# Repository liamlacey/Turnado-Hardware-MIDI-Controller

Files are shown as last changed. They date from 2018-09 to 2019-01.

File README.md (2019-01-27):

# Turnado Hardware MIDI Controller

This project is the development of a dedicated hardware MIDI controller for [Turnado](https://sugar-bytes.de/turnado) - a multi-award winning, real-time multi audio effect software plugin, developed by Berlin-based company Sugar Bytes. 

This was a project developed for the 2018 Hackaday Prize and was awarded as one of the top 20 projects for the Musical Instrument Challenge - see the project page [here](https://hackaday.io/project/160792-turnado-hardware-midi-controller).

This repo includes all code and design files for the project.

The project uses a [Teensy 3.6](https://www.pjrc.com/teensy/) microcontoller, and requries the following software and libraries to compile the code:
- [Arduino IDE](https://www.arduino.cc/en/Main/Software)
- [Teensyduino](https://www.pjrc.com/teensy/td_download.html) software add-on for Arduino IDE
- [Optimized ILI9341 TFT Library](https://github.com/PaulStoffregen/ILI9341_t3) for Arduino

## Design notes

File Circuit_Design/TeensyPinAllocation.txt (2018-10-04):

0 / RX1 	- UNUSED (keep spare for MIDI)
1 / TX1  	- UNUSED (keep spare for MIDI)
2 		- Preset down button
3 		- Preset up button
4 		- Randomise button
5 		- LCD enc 3 A
6 		- LCD enc 3 B
7 		- LCD enc 2 A
8 		- LCD enc 2 B
9 		- LCD D/C
10 / CS0 	- LCD CS
11 / MOSI0 	- LCD DSI/MOSI
12 / MISO0 	- LCD SDO/MISO
13 / SCK0 	- LCD SCK
14 / A0 	- Enc 6 switch
15 / A1 	- Enc 7 B
16 / A2 	- Enc 7 A
17 / A3 	- Enc 7 switch
18 / A4 	- JS 7
19 / A5 	- Enc 8 B
20 / A6 	- Enc 8 A
21 / A7 	- Enc 8 switch
22 / A8 	- JS 8
23 / A9 	- UNUSED 
24 		- LCD enc 1 switch
25 		- LCD enc 1 A 
26 		- LCD enc 1 B
27 		- Mix enc A
28 		- Mix enc B
29 		- Dictator enc switch
30 		- Dictator enc A
31 / A12 	- Dictator enc B
32 / A13 	- Dictator JS
33 / A14 	- JS 3
34 / A15 	- JS 4
35 / A16 	- Enc 5 B
36 / A17 	- Enc 5 A
37 / A18 	- Enc 5 switch
38 / A19 	- Enc 6 B
39 / A20 	- Enc 6 A
A21 		- JS 5
A22 		- JS 6

Inner row through-hole pins:
A10 		- UNUSED
A11 		- UNUSED

Surface mount pins:
40 		- Enc 1 A
41 		- Enc 2 B
42 		- Enc 2 switch
43 		- Enc 3 B
44 		- Enc 3 A
45 		- Enc 4 B
46 		- Enc 4 switch
47 		- Enc 4 A
48 		- Enc 3 switch
49 / A23 	- JS 2
50 / A24 	- JS 1
51 		- Enc 2 A
52 		- Enc 1 switch
53 		- Enc 1 B
54 		- UNUSED
55 		- UNUSED
56 		- UNUSED
57 		- UNUSED

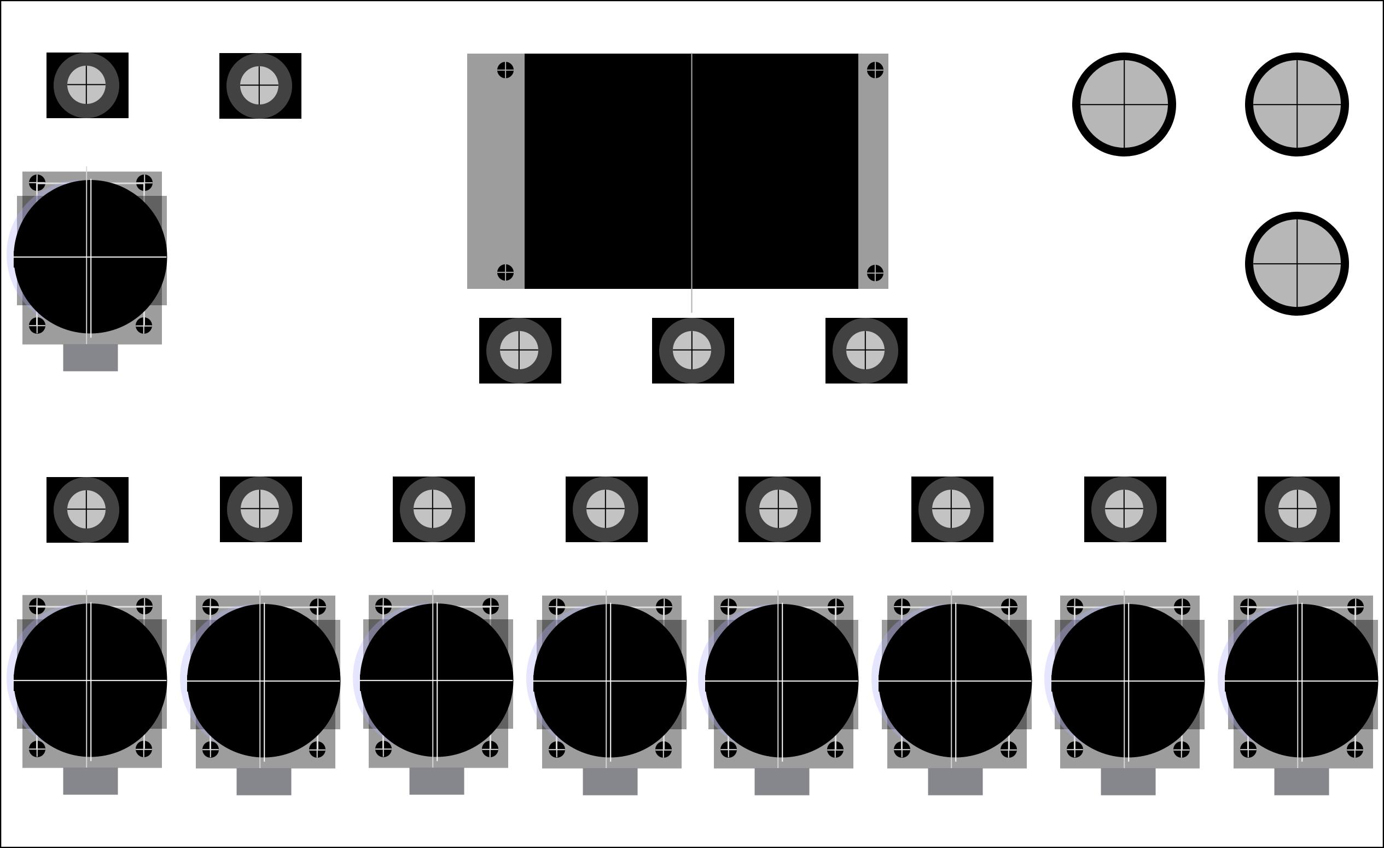
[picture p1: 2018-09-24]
Panel_Design/TurnadoHardwareControllerControlLayoutv2.png

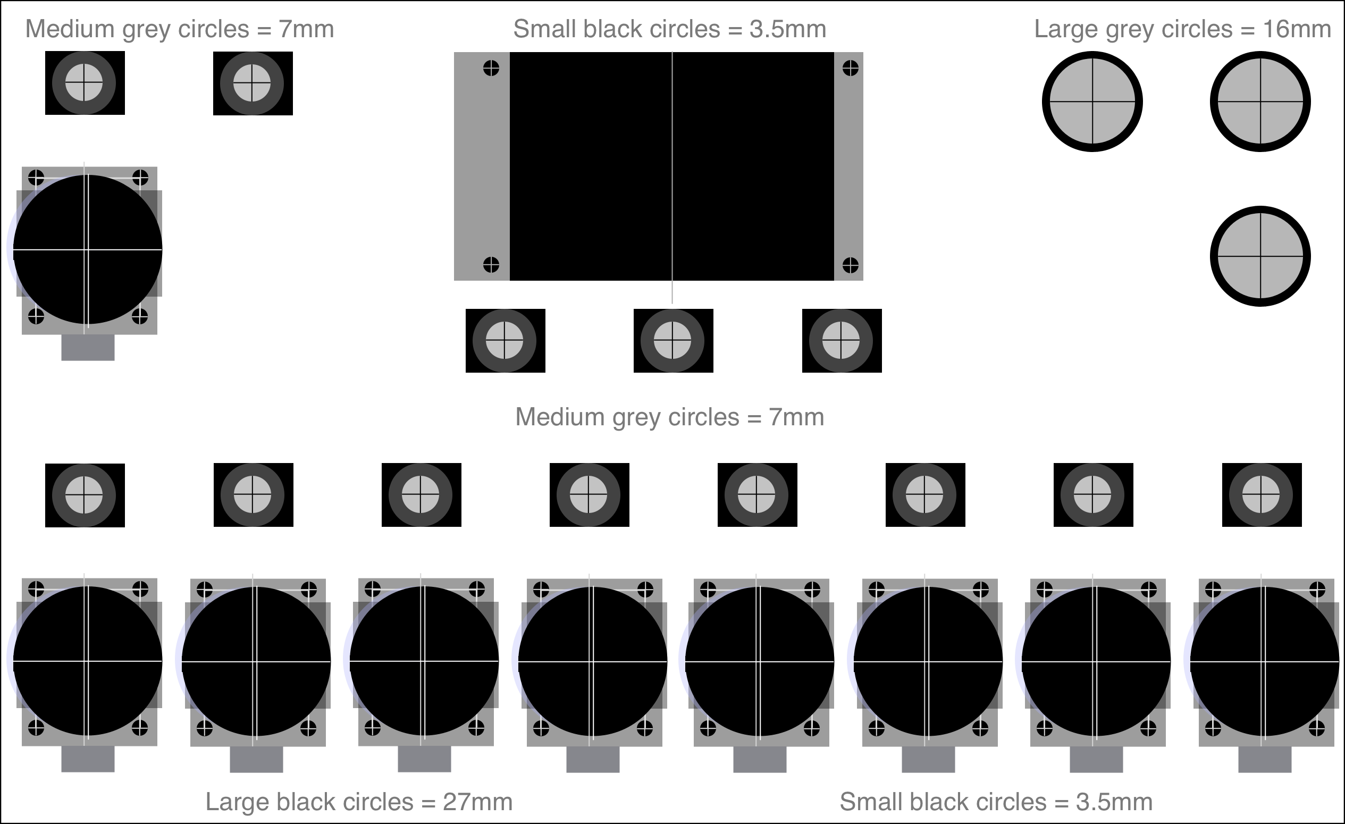
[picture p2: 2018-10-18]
Panel_Design/TurnadoHardwareControllerControlLayoutv2Annotated.png

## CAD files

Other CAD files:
Panel_Design/TurnadoHardwareControllerPanelHoles.dwg

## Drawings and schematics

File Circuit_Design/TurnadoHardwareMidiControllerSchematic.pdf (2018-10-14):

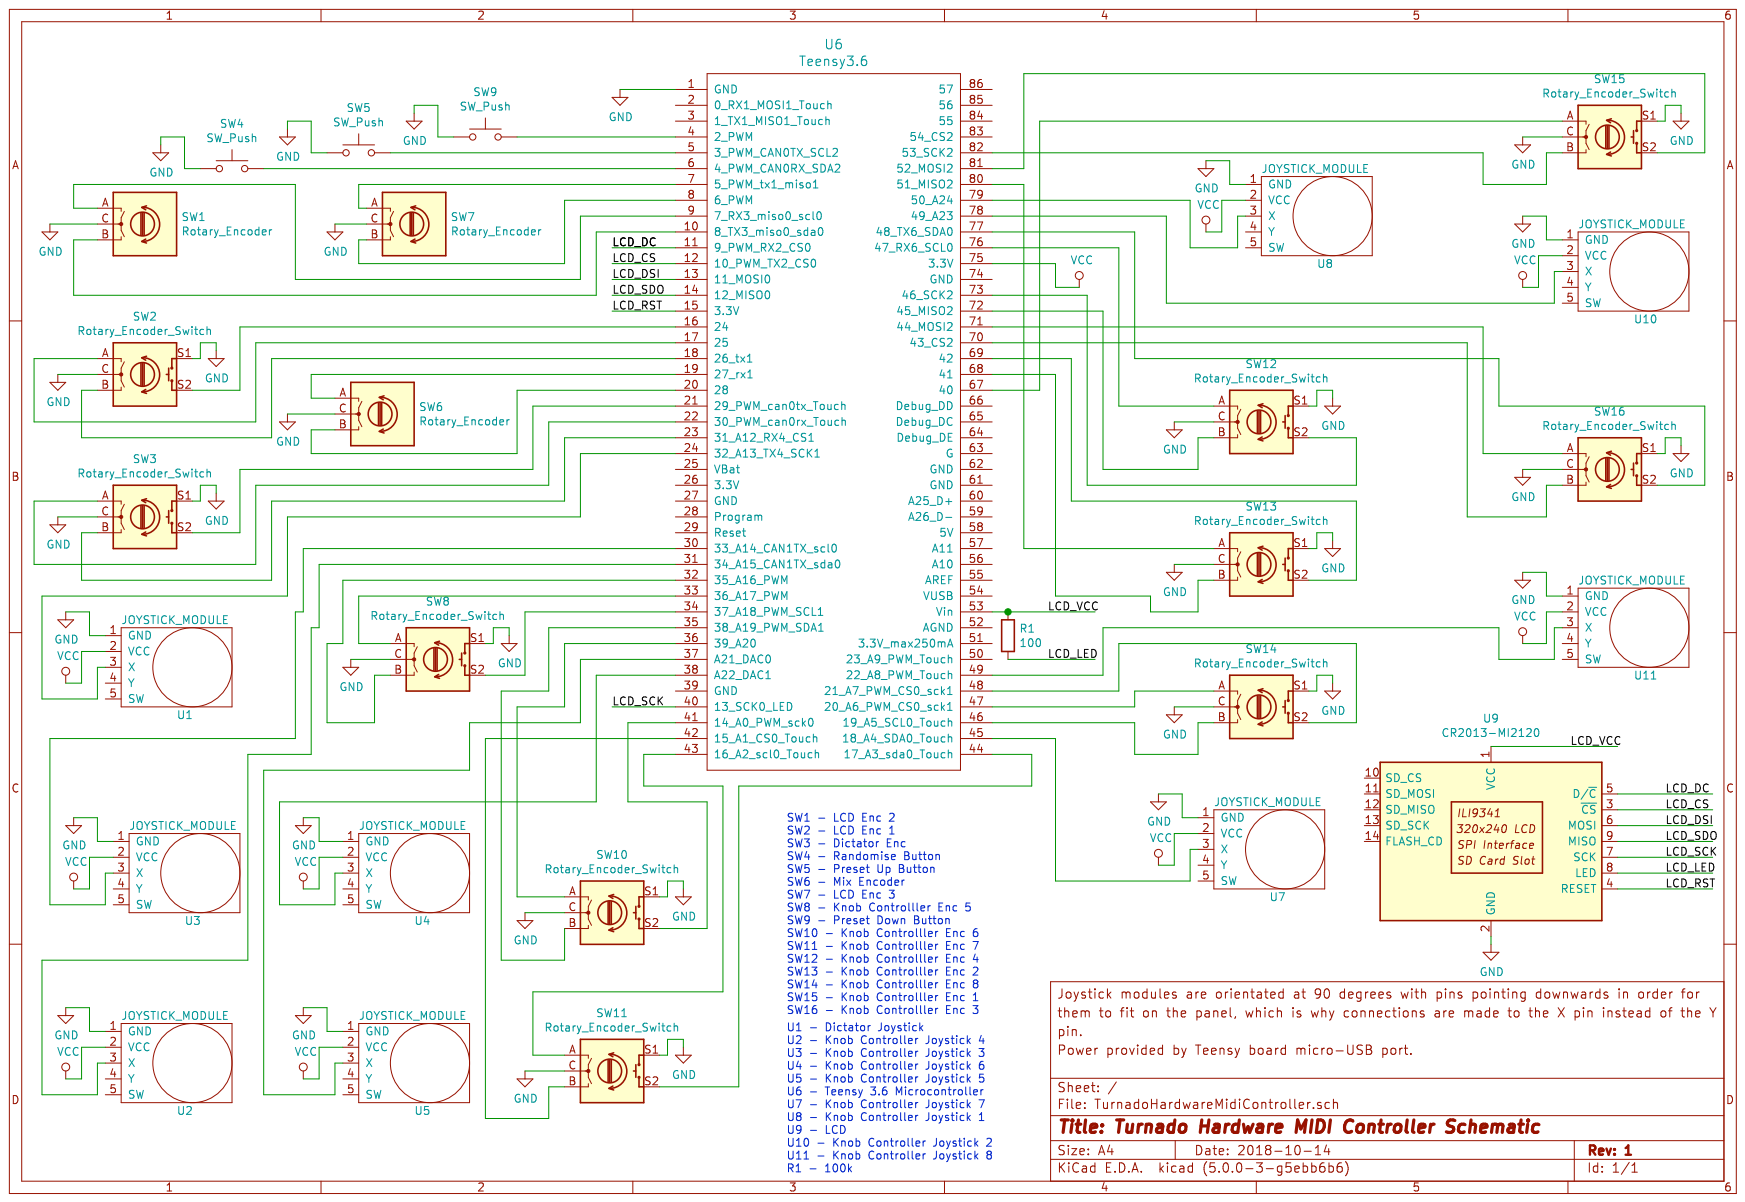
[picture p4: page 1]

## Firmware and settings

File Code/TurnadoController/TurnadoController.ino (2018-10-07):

#include "Globals.h"

//=========================================================================
//FIXME: make the below an array for each MIDI channel, where the index is set by the current MIDI channel of the program change buttons.
//This will involve needing to update the program display on the LCD top bar every time the program change buttons MIDI channel is changed.
int16_t currentMidiProgramNumber = 0;

//FIXME: could the below be replaced by knobControllerData and mixControllerData as arrays for each MIDI channel?
uint8_t deviceParamValuesForMidiChannel[16][NUM_OF_DEVICE_PARAMS] = {{0}};

//=========================================================================
#include "PinAllocations.h"
#include "Settings.h"

void setKnobControllerBaseValue (uint8_t index, uint8_t value, bool sendToMidiOut);
void setMixControllerValue (uint8_t value, bool sendToMidiOut);

#include "MidiIO.h"
#include "Lcd.h"
#include "Controls.h"

//=========================================================================
//=========================================================================
//=========================================================================
void setup()
{
#ifdef DEBUG
  Serial.begin(9600);
  delay(500);
#endif

  setupSettings();
  setupLcd();
  setupControls();
  setupMidiIO();

  for (uint8_t chan = 0; chan < 16; chan++)
  {
    //assume mix value always starts at 127, and the rest start at 0.
    deviceParamValuesForMidiChannel[chan][DEVICE_PARAM_INDEX_MIX] = 127;
  }
}

//=========================================================================
//=========================================================================
//=========================================================================
void loop()
{
  updateMidiIO();
  updateControls();
  updateLcd();
  settingsUpdateEeprom();
}

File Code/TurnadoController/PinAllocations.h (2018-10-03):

struct EncoderPins
{
  uint8_t pinA;
  uint8_t pinB;
  int8_t pinSwitch;
};

const EncoderPins PINS_KNOB_CTRL_ENCS[NUM_OF_KNOB_CONTROLLERS] =
{
  {.pinA = 40, .pinB = 53, .pinSwitch = 52}, //1
  {.pinA = 51, .pinB = 41, .pinSwitch = 42}, //2
  {.pinA = 44, .pinB = 43, .pinSwitch = 48}, //3
  {.pinA = 47, .pinB = 45, .pinSwitch = 46}, //4
  {.pinA = 36, .pinB = 35, .pinSwitch = 37}, //5
  {.pinA = 39, .pinB = 38, .pinSwitch = 14}, //6
  {.pinA = 16, .pinB = 15, .pinSwitch = 17}, //7
  {.pinA = 20, .pinB = 19, .pinSwitch = 21}, //8
  {.pinA = 30, .pinB = 31, .pinSwitch = 29}  //dictator
};

const EncoderPins PINS_MIX_ENC =
{
  .pinA = 27,
  .pinB = 28,
  .pinSwitch = -1
};

const EncoderPins PINS_LCD_ENCS[NUM_OF_LCD_ENCS] =
{
  {.pinA = 25, .pinB = 26, .pinSwitch = 24},  //Control
  {.pinA = 7, .pinB = 8, .pinSwitch = -1},    //Paramater
  {.pinA = 5, .pinB = 6, .pinSwitch = -1},    //Value

};

const uint8_t PINS_KNOB_CTRL_JOYSTICKS[NUM_OF_KNOB_CONTROLLERS] =
{
  A24, //1
  A23, //2
  A14, //3
  A15, //4
  A21, //5
  A22, //6
  A4,  //7
  A8,  //8
  A13, //dictator
};

const uint8_t PIN_PRESET_UP_BUTTON = 3;
const uint8_t PIN_PRESET_DOWN_BUTTON = 2;

const uint8_t PIN_RANDOMISE_BUTTON = 4;

const uint8_t PIN_LCD_DC = 9;
const uint8_t PIN_LCD_CS = 10;

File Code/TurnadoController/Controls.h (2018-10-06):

#include "RotaryEncoder.h"
#include "SwitchControl.h"
#include "ThumbJoystick.h"

//=========================================================================
//DEV STUFF...
//#define DISABLE_JOYSTICKS 1

//=========================================================================
RotaryEncoder* knobControllersEncoders[NUM_OF_KNOB_CONTROLLERS];
ThumbJoystick* knobControllersJoysticks[NUM_OF_KNOB_CONTROLLERS];

RotaryEncoder* mixEncoder;

RotaryEncoder* lcdEncoders[NUM_OF_LCD_ENCS];

SwitchControl* presetUpButton;
SwitchControl* presetDownButton;

SwitchControl* randomiseButton;

//=========================================================================
//FIXME: could knobControllerData and mixControllerData be arrays for each MIDI channel and replace deviceParamValuesForMidiChannel?

struct KnobControllerData
{
  int16_t baseValue = 0;
  uint8_t prevBaseValue = 0;
  int16_t relativeValue = 0;
  int8_t prevRelativeValue = 0;
  int16_t combinedMidiValue = 0;
  uint8_t prevCombinedMidiValue = 0;
};

KnobControllerData knobControllerData[NUM_OF_KNOB_CONTROLLERS];
bool ignoreJsMessage[NUM_OF_KNOB_CONTROLLERS] = {false};

struct MixControllerData
{
  int16_t midiValue = 127;
  uint8_t prevMidiValue = 127;
};

MixControllerData mixControllerData;

uint8_t randomiseButtonState = 0;
bool ignoreNextRandomiseButtonRelease = false;

uint8_t presetUpButtonState = 0;
uint8_t presetDownButtonState = 0;
bool ignoreNextPresetButtonRelease = false;

enum PresetButtonType
{
  PRESET_BUTTON_TYPE_DOWN = 0,
  PRESET_BUTTON_TYPE_UP
};

//=========================================================================
void processEncoderChange (RotaryEncoder &enc, int enc_value);
void processEncoderSwitchChange (RotaryEncoder &enc);
void processPushButtonChange (SwitchControl &switchControl);
void processJoystickChange (ThumbJoystick &thumbJoystick, bool isYAxis);
void setGlobalMidiChannel (int8_t incVal);

//=========================================================================
//=========================================================================
//=========================================================================
void setupControls()
{
  for (auto i = 0; i < NUM_OF_KNOB_CONTROLLERS; i++)
  {
    knobControllersEncoders[i] = new RotaryEncoder (PINS_KNOB_CTRL_ENCS[i].pinA, PINS_KNOB_CTRL_ENCS[i].pinB, PINS_KNOB_CTRL_ENCS[i].pinSwitch);
    knobControllersEncoders[i]->onEncoderChange (processEncoderChange);
    knobControllersEncoders[i]->onSwitchChange (processEncoderSwitchChange);

    knobControllersJoysticks[i] = new ThumbJoystick (PINS_KNOB_CTRL_JOYSTICKS[i]);
    knobControllersJoysticks[i]->onJoystickChange (processJoystickChange);
  }

  mixEncoder = new RotaryEncoder (PINS_MIX_ENC.pinA, PINS_MIX_ENC.pinB, PINS_MIX_ENC.pinSwitch);
  mixEncoder->onEncoderChange (processEncoderChange);
  lcdSetSliderValue (LCD_SLIDER_MIX_INDEX, mixControllerData.midiValue);

  for (auto i = 0; i < NUM_OF_LCD_ENCS; i++)
  {
    lcdEncoders[i] = new RotaryEncoder (PINS_LCD_ENCS[i].pinA, PINS_LCD_ENCS[i].pinB, PINS_LCD_ENCS[i].pinSwitch);
    lcdEncoders[i]->onEncoderChange (processEncoderChange);
    lcdEncoders[i]->onSwitchChange (processEncoderSwitchChange);
  }

  presetUpButton = new SwitchControl (PIN_PRESET_UP_BUTTON);
  presetUpButton->onSwitchStateChange (processPushButtonChange);
  presetDownButton = new SwitchControl (PIN_PRESET_DOWN_BUTTON);
  presetDownButton->onSwitchStateChange (processPushButtonChange);

  randomiseButton = new SwitchControl (PIN_RANDOMISE_BUTTON);
  randomiseButton->onSwitchStateChange (processPushButtonChange);

  //setupSettings() must be called before setupControls() for the below to be set correctly.
  currentMidiProgramNumber = settingsData[SETTINGS_PRESET].paramData[PARAM_INDEX_START_NUM].value;
}

//=========================================================================
//=========================================================================
//=========================================================================
void updateControls()
{
  for (auto i = 0; i < NUM_OF_KNOB_CONTROLLERS; i++)
  {
    knobControllersEncoders[i]->update();

#ifndef DISABLE_JOYSTICKS
    knobControllersJoysticks[i]->update();
#endif
  }

  mixEncoder->update();

  for (auto i = 0; i < NUM_OF_LCD_ENCS; i++)
  {
    lcdEncoders[i]->update();
  }

  presetUpButton->update();
  presetDownButton->update();
  randomiseButton->update();
}

//=========================================================================
//=========================================================================
//=========================================================================
void setKnobControllerCombinedMidiValue (uint8_t index, bool sendToMidiOut)
{
  if (knobControllerData[index].relativeValue > 0)
    knobControllerData[index].combinedMidiValue = map (knobControllerData[index].relativeValue, 0, 127, knobControllerData[index].baseValue, 127);
  else if (knobControllerData[index].relativeValue < 0)
    knobControllerData[index].combinedMidiValue = map (knobControllerData[index].relativeValue, 0, -128, knobControllerData[index].baseValue, 0);
  else
    knobControllerData[index].combinedMidiValue = knobControllerData[index].baseValue;

  if (knobControllerData[index].combinedMidiValue != knobControllerData[index].prevCombinedMidiValue)
  {
    if (sendToMidiOut)
    {
      //send MIDI message
      byte channel = settingsData[index + 1].paramData[PARAM_INDEX_MIDI_CHAN].value;
      if (channel == 0)
        channel = settingsData[SETTINGS_GLOBAL].paramData[PARAM_INDEX_MIDI_CHAN].value;
      byte control = settingsData[index + 1].paramData[PARAM_INDEX_CC_NUM].value;
      byte value = knobControllerData[index].combinedMidiValue;
      sendMidiCcMessage (channel, control, value, index);

    } //if (sendToMidiOut)

    //update LCD display
    lcdSetSliderValue (index, knobControllerData[index].combinedMidiValue);

    knobControllerData[index].prevCombinedMidiValue = knobControllerData[index].combinedMidiValue;

  } //if (knobControllerData[index].combinedMidiValue != knobControllerData[index].prevCombinedMidiValue)
}

//=========================================================================
//=========================================================================
//=========================================================================
void setKnobControllerBaseValue (uint8_t index, uint8_t value, bool sendToMidiOut)
{
  knobControllerData[index].baseValue = value;

  if (knobControllerData[index].baseValue != knobControllerData[index].prevBaseValue)
  {
    setKnobControllerCombinedMidiValue (index, sendToMidiOut);
    knobControllerData[index].prevBaseValue = knobControllerData[index].baseValue;
  }
}
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

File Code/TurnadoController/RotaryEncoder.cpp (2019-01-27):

#include "RotaryEncoder.h"

RotaryEncoder::RotaryEncoder (uint8_t encPin1, uint8_t encPin2, int8_t switchPin)
{
  encoder = new Encoder (encPin1, encPin2);

  if (switchPin >= 0)
  {
    switchDebouncer = new Bounce (switchPin, DEBOUNCE_TIME);
    pinMode (switchPin, INPUT_PULLUP);
  }
  else
  {
    switchEnabled = false;
  }
}

RotaryEncoder::~RotaryEncoder()
{
  delete encoder;

  if (switchEnabled)
    delete switchDebouncer;
}

void RotaryEncoder::update()
{
  //Check for encoder turn

  int env_val = encoder->read();

  //If there is an encoder value change
  if (env_val >= 4 || env_val <= - 4)
  {
    if (accelerationEnabled)
    {
      //get time interval between this change and previous change
      currentTime = millis();
      revolutionTime = currentTime - prevTime;
      prevTime = currentTime;

      // trigger acceleration only when encoder speed is sufficiently high (small time value)
      if (revolutionTime < revTimeThreshold)
      {
        rev = revTimeThreshold - revolutionTime;
        b = (int)a * rev + c; //slope of a line equation
        env_val = env_val * b; //apply acceleration
      }

    } //if (accelerationEnabled)

    env_val /= 4;

    //constrain value to expected range to get rid of occasional incorrect large encoder readings
    env_val = constrain (env_val, -4, 4);

    if (shouldSendEncoderValue (env_val))
    {
      this->handle_encoder_change (*this, env_val);
    }

    encoder->write(0);

  } //if (env_val >= 4 || env_val <= - 4)

  if (switchEnabled)
  {
    //Check for switch state change
    switchDebouncer->update();

    if (switchDebouncer->risingEdge())
    {
      switchState = 0;
      this->handle_switch_change (*this);
    }
    else if (switchDebouncer->fallingEdge())
    {
      switchState = 1;
      this->handle_switch_change (*this);
    }

  }//if (switchEnabled)

}

uint8_t RotaryEncoder::getSwitchState()
{
  return switchState;
}

void RotaryEncoder::onEncoderChange( void (*function)(RotaryEncoder&, int) )
{
  this->handle_encoder_change = function;
}

void RotaryEncoder::onSwitchChange( void (*function)(RotaryEncoder&) )
{
  this->handle_switch_change = function;
}

bool RotaryEncoder::operator==(RotaryEncoder& b)
{
  return (this == &b);
}

void RotaryEncoder::enableAcceleration (bool shouldEnable)
{
  accelerationEnabled = shouldEnable;
}

bool RotaryEncoder::shouldSendEncoderValue (int incVal)
{
  //Only send the encoder value if it's the first turn after a certain time period or if
  //the direction is the same as with the previous x amount of turns.
  //This is done to prevent stray sets of positive values within fast negative turns from being processed.

  bool shouldSend = false;

  //if the first encoder turn after a certain time period
  if (millis() - prevIncTime >= 50)
  {
    shouldSend = true;

    //set all prevIncDirs to match incVal to reset process of checking previous values
    for (uint8_t i = 0; i < NUM_OF_PREV_VALS; i++)
      incVal > 0 ? prevIncDirs[i] = 1 : prevIncDirs[i] = -1;
  }

  //else if the value direction matches that of the previous set of values
  else if (doesValDirMatchPrevVals (incVal))
  {
    shouldSend = true;

    //move all values in prevIncDirs backward (removing end/oldest value)
    //and add new value based on incVal at the beginning

    for (uint8_t i = NUM_OF_PREV_VALS - 1; i > 0; i--)
      prevIncDirs[i] = prevIncDirs[i - 1];

    incVal > 0 ? prevIncDirs[0] = 1 : prevIncDirs[0] = -1;
  }

  prevIncTime = millis();
  return shouldSend;
}

bool RotaryEncoder::doesValDirMatchPrevVals (int incVal)
{
  int8_t valDir = incVal > 0 ? 1 : -1;

  for (uint8_t i = 0; i < NUM_OF_PREV_VALS; i++)
  {
    if (valDir != prevIncDirs[i])
      return false;
  }

  return true;
}

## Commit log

2018-09-01 Created a Teensy sketch to test the ILI9341 2.4" TFT LCD I want to use. Sketch uses the Teensy optimised ILI9341 library and draws a rectangle of a size based on a recieved USB MIDI CC value.
2018-09-01 Now displaying 8 sliders that are each controlled by their own MIDI CC (currently mapped to my nanoKONTROL sliders).
2018-09-01 Now doing all LCD display updating from the main loop at a set frame rate (rather than each time a MIDI message is received), as this is probably the way it should be done (in order to prevent extens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
    [ILI9341_TFT_LCD_test.ino]
2018-09-09 Created a class for processing encoder interactions. Needs some refining and documentation. Testing this in a new Arduino sketch that will become the controller sketch.
2018-09-09 Created a class for handling standard binary switches/buttons.
2018-09-09 Changed name of the EncoderSwitch class
2018-09-09 Got joystick processing working correctly. Adjust plateau values - might need adjusting still.
    [ThumbJoystick.cpp]
2018-09-12 Created a PinAllocations.h file for defining all pin allocations.
2018-09-12 Modified RotaryEncoder class to take a switch pin value of -1 if the switch isn't being used. Untested.
2018-09-12 Changed the rotary encoder switch change callback to no longer pass the switch value, as this can be access from the class ref that's passed (like with the joystick and button classes). Can't do this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
    [RotaryEncoder.cpp, RotaryEncoder.h]
2018-09-12 Added very basic code for the LCD. At the moment it just fills it black and calls it's update function at a set frame rate, however the update function currently doesn't do anything. Untested.
    [TurnadoController.ino]
2018-09-12 Added USB-MIDI reading of CC messages. Currently just prints the received message. Untested.
2018-09-13 Added dev defines for disabling USB MIDI and joysticks. Drawing test text on the LCD (not sure if this is the best way to draw text - need to investigate). Fixed issue where I hadn't added callbacks 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
    [TurnadoController.ino]
2018-09-13 Completely remapped the pin allocation based on position of controls on panel and orientation of teensy in enclosure (USB port on right side).
2018-09-13 Started building the LCD menu, and got the first column to be controllable with the 1st LCD encoder.
2018-09-14 Replace all LCD menu data with the new settings data
    [Lcd.h]
2018-09-14 Values on the menu can now be changed with the value encoder and are saved to EEPROM periodically.
2018-09-16 Implemented knob controller encoder switches (reset base value). Fixed issue where base value only changes wouldn't send MIDI messages. Increased debounce time of rotary encoder switches. All unteste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
    [Controls.h, RotaryEncoder.h]
2018-09-16 Implemented mix encoder. Untested.
2018-09-16 Implemented randomise button. Untested.
2018-09-16 Implemented basic preset up and down button implementation. Untested.
2018-09-16 Implemented handling pressing both preset buttons simultaneously to resend current program number. Untested.
2018-09-16 Implemented a blank 'controls' LCD display, which can be switched to and from the menu display using LCD encoder 1 switch. Turning LCD controls whilst not on menu will also switch to menu.
2018-09-16 Populated the controls display with 10 sliders (8 knob controllers, dictator, and mix) along with text labelling each slider. Implemented updating of the knob controller sliders with internal midi va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
2018-09-16 Increased the length of the horizontal sliders to 254 (a multiple of 127) to prevent drawing issues when rounding floats to ints.
    [Lcd.h]
2018-09-16 Fixed issue where MIDI messages weren't being sent on the global channel if set to.
    [Controls.h]
2018-09-16 Fixed issue where knob controller encoder switch code was being called on every LCD ctrl encoder switch press.
    [Controls.h]
2018-09-16 Sliders are now showing their correct values when switching back to the control display.
    [Lcd.h]
2018-09-16 Added a bar at the top of the display for displaying current global MIDI channel and MIDI program. Currently only updating when switching to the controls page. Changed the position of the horixontal 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
2018-09-18 Implemented rotary encoder acceleration, as well as a function to turn it off.
2018-09-24 Added PSD and PNG files of panel control layout for drilling the enclosure.
2018-09-25 Triggering an EEPROM save if using the LCD encoder switch to move away from menu display. Untested.
2018-09-27 Implemented randomise + preset button combination for changing global MIDI channel. Untested.
2018-10-03 Wired all encoder A and B connections the wrong way round, so switched the pin numbers.
    [PinAllocations.h]
2018-10-04 Increased joystick hysterisis and centre plateau values to improve joystick performance.
2018-10-04 Added Teensy 3.6 pin allocation
2018-10-04 Improved formatting of pin allocation file for git.
2018-10-05 Fixed non-centring joystick issue.
    [ThumbJoystick.cpp]
2018-10-05 Fixed LCD issues with centre line on LCD.
    [Lcd.h]
2018-10-05 Fixed issue where randomise button wasn't working.
    [Controls.h]
2018-10-06 Fixed issue where in some scenarios the 'reset knob controller' message wouldn't reset the value in Turnado (see comment in code for reason).
    [Controls.h, RotaryEncoder.cpp]
2018-10-06 Implemented a second behaviour of the knob controller encoder switches, where if the knob controller joystick is currently being used the switch will set the base value to be the current combined val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
2018-10-06 Fixed issue where joysticks wouldn't always send min and max user values.
    [ThumbJoystick.cpp]
2018-10-06 Increased JS centre plateau value to improve performance of joysticks.
2018-10-06 Implemented storage of param values for each MIDI channel so that when switching MIDI channel (globally or per control) the correct param values are recalled.
    [Controls.h, Lcd.h, TurnadoController.ino]
2018-10-07 Added a FIXME regarding current MIDI program number implementation.
    [TurnadoController.ino]
2018-10-14 Added circuit schematic
    [TurnadoHardwareMidiController.sch]
2018-10-18 Added panel design DWG file and annotated version of original panel design PNG file
    [TurnadoHardwareControllerPanelHoles.dwg]
2019-01-27 Improved rotary encoder value processing to improve performance of the encoders (particularly to fix issues with certain encoders sending large positive values when being turn fast in the negative di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
    [RotaryEncoder.cpp, RotaryEncoder.h]
